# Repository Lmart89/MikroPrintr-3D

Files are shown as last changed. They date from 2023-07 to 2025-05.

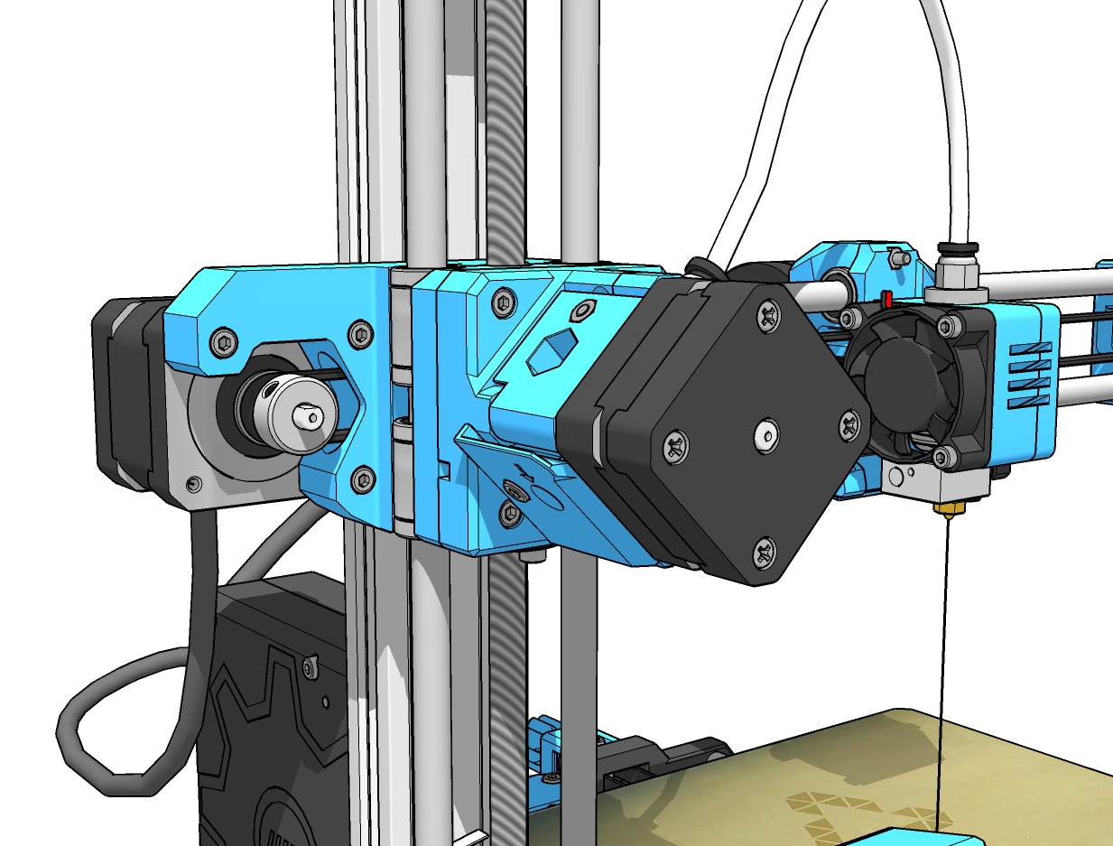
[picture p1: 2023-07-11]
Printable Parts/ME_Mini_3D_Printer/images/ME_-_mini_-_15.jpg

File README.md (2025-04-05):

<p align="center">
<img src=https://github.com/Lmart89/MikroPrintr-3D/assets/42391946/adc98b10-5be8-494d-9cd8-6f2932e612d1">
</p>

# MikroPrinter-3D.
## Una placa controladora de impresion 3d de bajo coste basada en Arduino.

<p align="center">

      

</p>

## 💡 Origen del Concepto

Mikropintr es el resultado propio de ideas tomadas de proyectos como Sinaptec (https://reprap.org/wiki/SinapTec), Morpheus (https://github.com/pscrespo/Morpheus-STM32) entre otros que ofrecen una solucion compacta y de bajo coste para la construccion de una placa controladora de impresion 3D. Sin embargo el gran limitante de estas placas es la necesidad de modificar el firmware para lograr compatiblidad con estos dispositovos, algo que requiere de mucho trabajo mas alla de la personalizacion, sin contar con los bugs resultantes en el proceso.
MikroPrintr pretende ofrecer una solucion asequible, a la vez de ser 100% compatible con Marlin, permitiendo desarrollar todo el potencial y la personalizacion a gusto. Para quepueda ser una placa compacta se opto por el arduino mega 2560 pro, una version reducida de Arduino Mega.

## :heavy_check_mark: Características de MikroPrintr.

- MCU: Arduino Mega 2560 Pro-Micro. Un Arduino Mega reducido en tamaño.

- Soporte Estándar de Marlin 2.0

- Diseñada bajo el standar RAMPS 1.4.

- Fabricación para uso de componentes THT (Trough Hole). 

- Tamaño Reducido. 103 mm x 90mm. a 1 sola capa, o producir a dos capas si se desea.

- Soporte Estándar de la smart reprap controller (lcd 2004) o la smart reprap full graphic controller (lcd 12864). no necesita la placa adaptadora para la conexion.
  
- Soporte para Módulo Wifi (esp8266-01 o esp8266-01s) Se recomienda la versión Esp-01s. se requiere un regulador de nivel lógico de 5v a 3.3V.

## :chart_with_upwards_trend: Estado del Proyecto.

   

:construction: Proyecto en construcción :construction:

## :books: Registro de cambios

###  Abril 2025.
- Se optimizo el diseño de la placa, y se corrigieron algunos detalles menores de la circuiteria.
- Rediseño de las piezas de la impresora con nuevas medidas, por un error de medicion en algunas de ellas.
- se libera la version 1H. de la placa.  

## :books: Recursos adicionales.

los siguientes modelos de impresoras pueden dar una fuente de inspiracion para el montaje  o diseño de una impresora 3d. uselos segun discrecion y precaucion propias.

### Me Mini 3d Printer - la mas completa y compleja.
  
 featured_preview_ME_-_mini_-_12

:earth_americas: link oficial. https://www.thingiverse.com/thing:5140212. 

### Skylab2 - una construccion sencilla y simple, recomendada para empezar. 

skylab2_1

:earth_americas: link oficial. https://www.thingiverse.com/thing:4624533.

### Prusa mini- la version mini de la prusa i3.
   Requiere la mayoria de sus piezas en ABS. 

prusa_mini

🌎 sitio oficial: https://www.printables.com/es/model/57214-mini-printable-parts/files

los archivos stl de estos modelos se encuentran en la carpeta "printable parts".

## :hammer_and_pick: Proyectos en conjunto. 
De momento estoy trabajando en el desarrollo de un software host propio para manejar la placa.

Si te interesa mi proyecto y deseas colaborar en el desarrollo, puedes contactarme, dejandome un mensaje o un request o solicitud de cambio via github.

Deseo que este proyecto pueda ser de utilidad para ti, maker. con :heart: desde Colombia 🇨🇴 para el mundo 🌎. :smile:

### <h4> :heavy_exclamation_mark: al hacer uso de los archivos publicados en este repositorio, el usuario acepta y asume su propia responsabilidad y riesgo por el uso y/o manipulacion de los archivos ofrecidos en este repositorio. :heavy_exclamation_mark: </h>

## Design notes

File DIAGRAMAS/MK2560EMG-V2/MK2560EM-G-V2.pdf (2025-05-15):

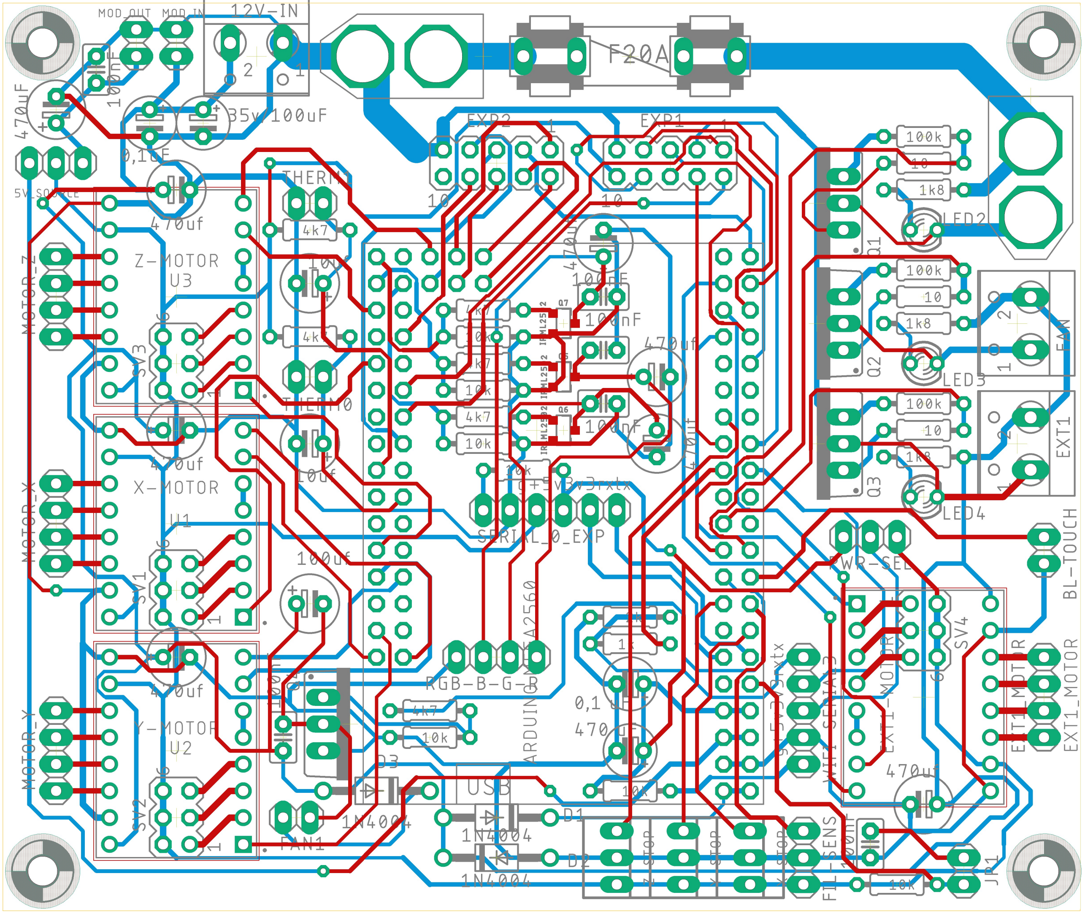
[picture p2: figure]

15/05/2025 3:54 p. m. f=2.00 D:\SOFT\MikroPrintr-3D-main\MikroPrintr-3D-main\DIAGRAMAS\MK2560EM-V2\MK2560EM-G v2.brd

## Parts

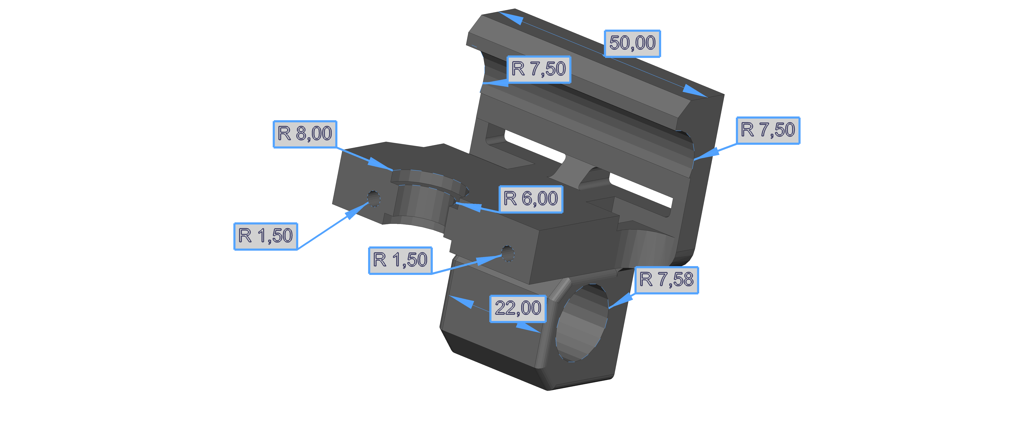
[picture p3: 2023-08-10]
Printable Parts/Skylab Variant/medidas_skylab/Extrusor_12 dimensiones 2.png

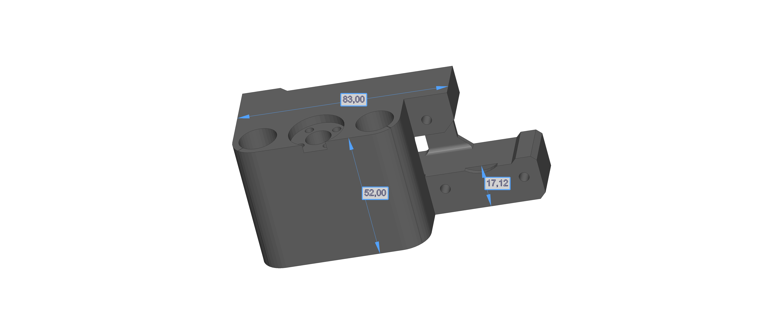
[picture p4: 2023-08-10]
Printable Parts/Skylab Variant/medidas_skylab/Z1 dimensiones 4.png

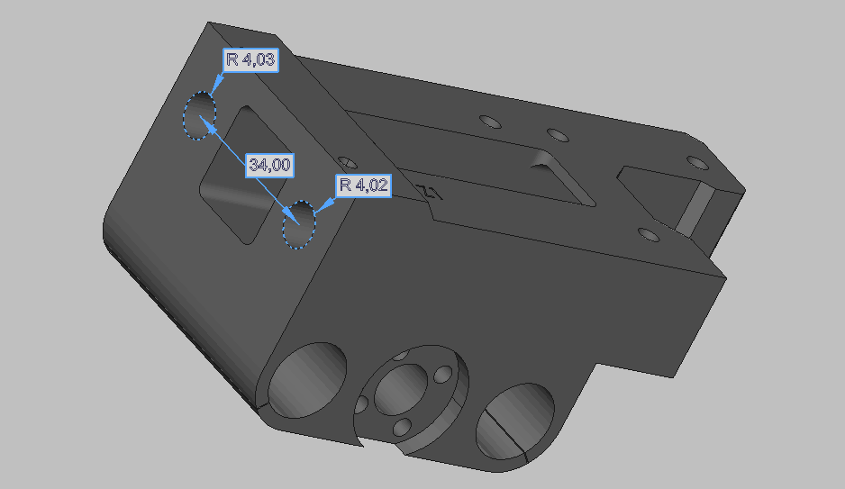
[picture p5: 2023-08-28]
Printable Parts/Skylab Variant/medidas_skylab/z1 dimensiones 5.png

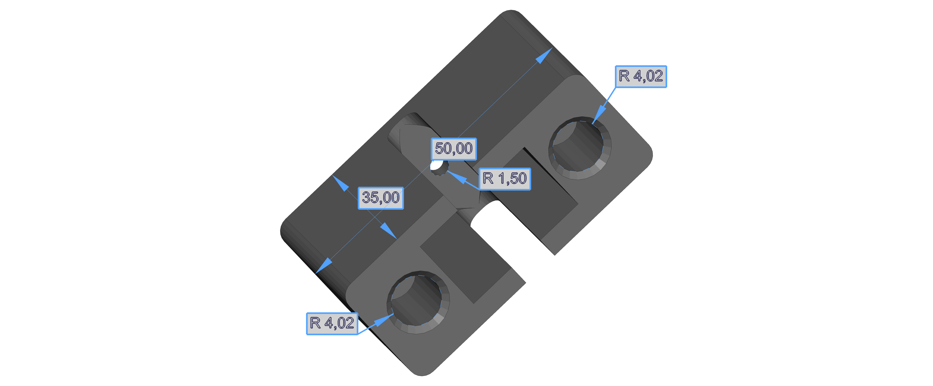
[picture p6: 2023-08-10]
Printable Parts/Skylab Variant/medidas_skylab/EjeX_polea dimensiones 1.png

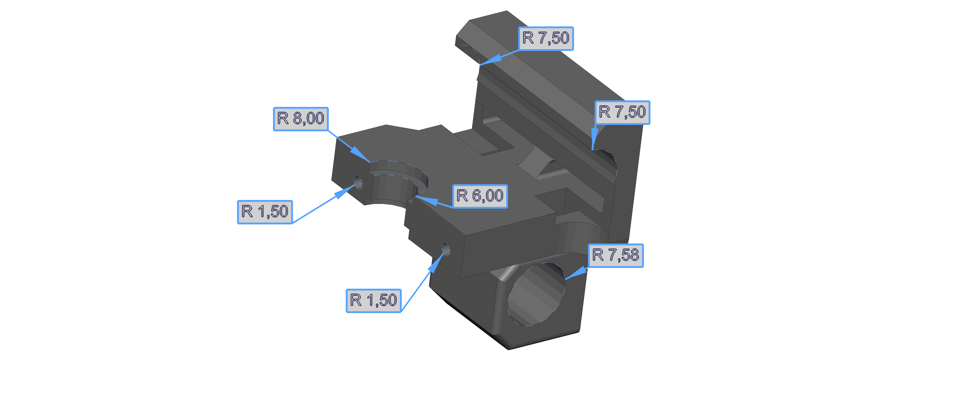
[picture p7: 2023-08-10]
Printable Parts/Skylab Variant/medidas_skylab/Extrusor_12 dimensiones 1.png

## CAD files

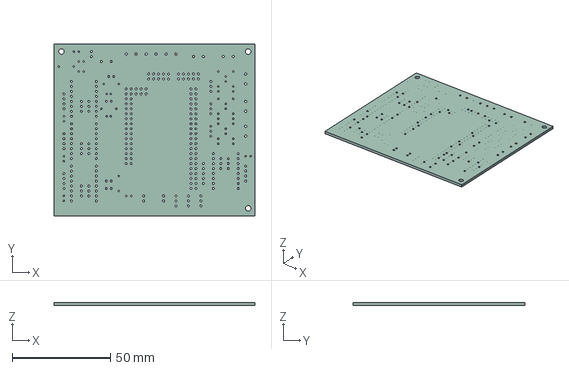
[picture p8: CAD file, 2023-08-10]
3D RENDERS/MK2560EM-G v1G-FLAT_PCB.step
102.5 x 87.6 x 1.60 mm

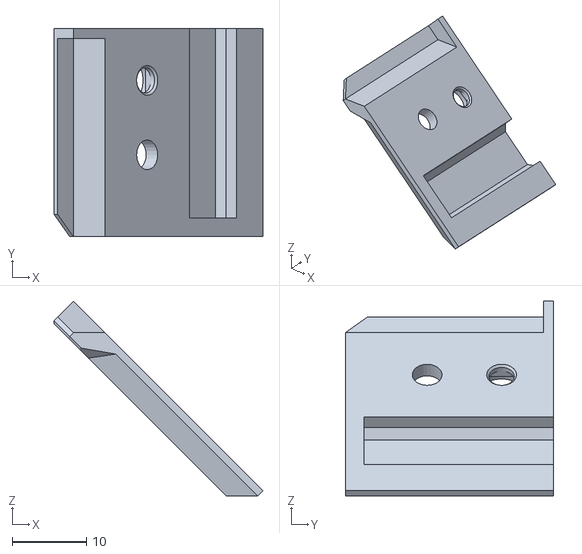
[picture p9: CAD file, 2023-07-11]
Printable Parts/ME_Mini_3D_Printer/files/Blue_-_Filament_Sensor_Cover.stl
28.1 x 28.0 x 26.2

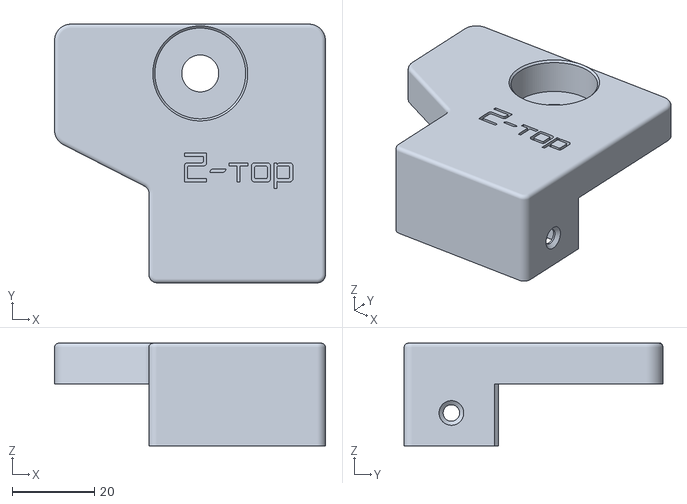
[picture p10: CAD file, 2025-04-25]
Printable Parts/MK-Parts V2/mk_z_top.stl
66.0 x 63.0 x 25.0

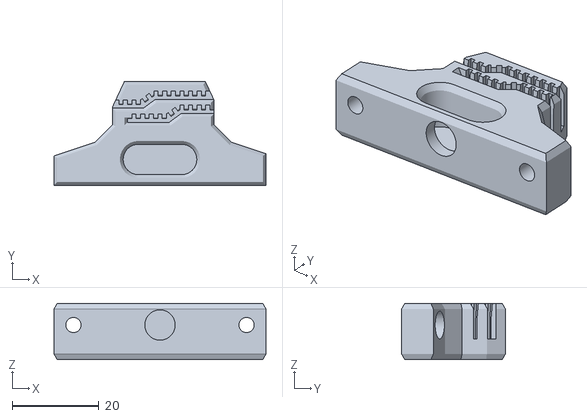
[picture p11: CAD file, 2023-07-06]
Printable Parts/Skylab Variant/MINI-y-belt-holder.stl
49.0 x 24.0 x 13.0

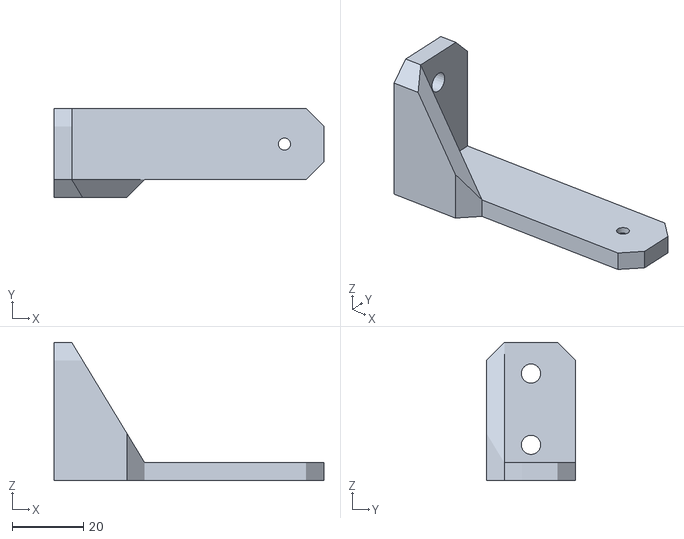
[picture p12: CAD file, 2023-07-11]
Printable Parts/ME_Mini_3D_Printer/files/Black_-_PSU_Left_Bracket.stl
75.7 x 25.0 x 38.7

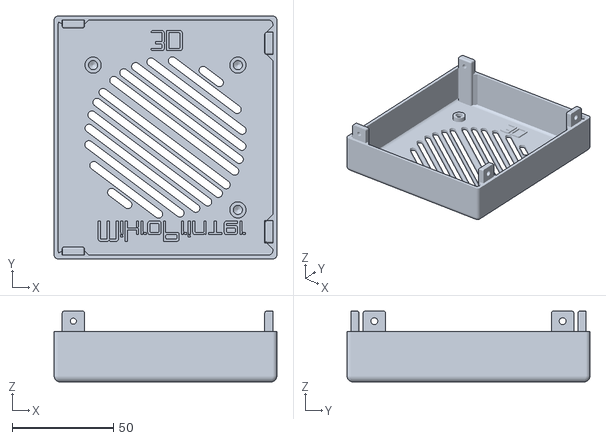
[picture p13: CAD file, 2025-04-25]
Printable Parts/MK-Parts V2/mk-board-case-top.stl
110.0 x 120.0 x 35.0

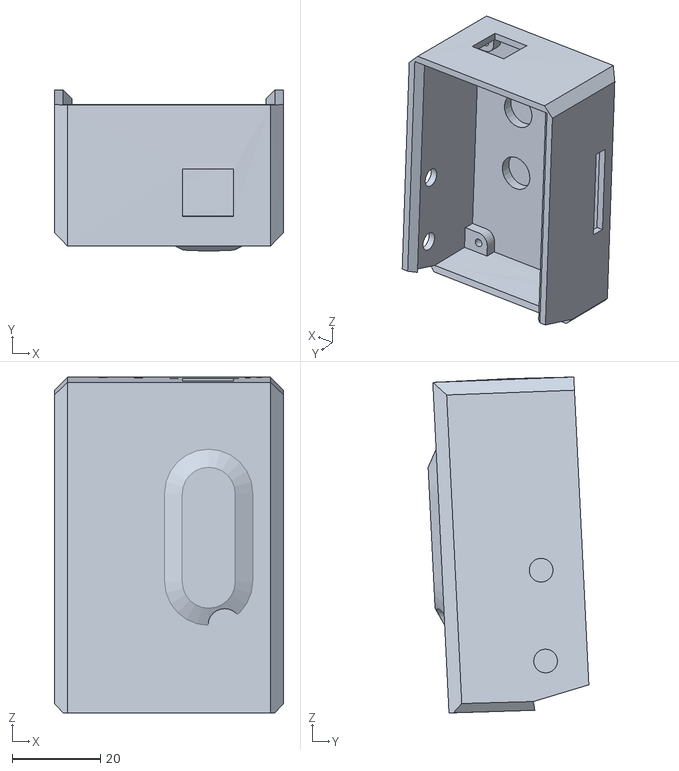
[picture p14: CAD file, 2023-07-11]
Printable Parts/ME_Mini_3D_Printer/files/Black_-_MKS_Adaptor_Housing.stl
52.0 x 36.4 x 76.2

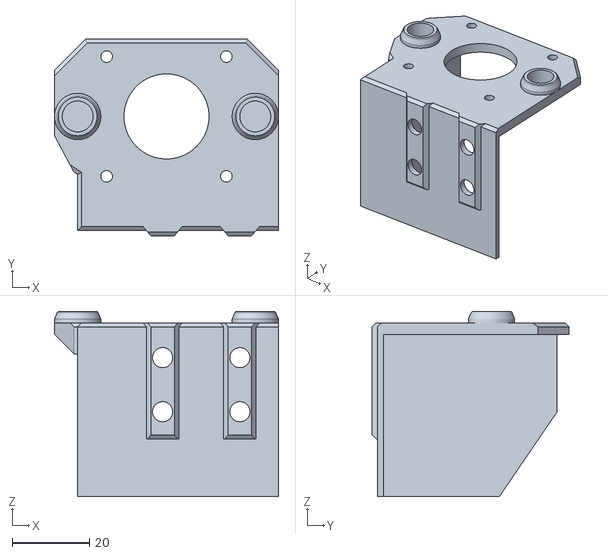
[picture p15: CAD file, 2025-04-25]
Printable Parts/MK-Parts V2/mk-z-motor-mount.stl
58.0 x 50.9 x 48.0

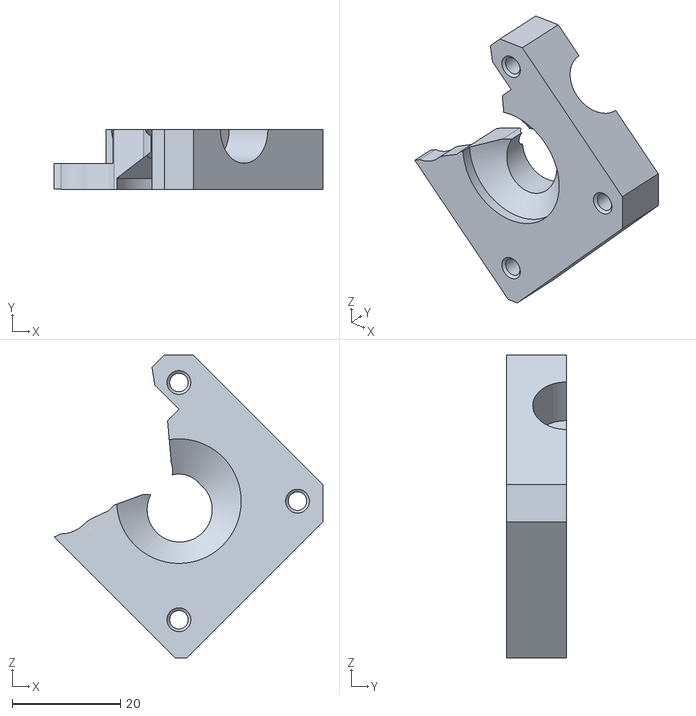
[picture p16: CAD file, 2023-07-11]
Printable Parts/ME_Mini_3D_Printer/files/Blue_-_Extruder_Motor_Mount.stl
49.7 x 11.0 x 56.0

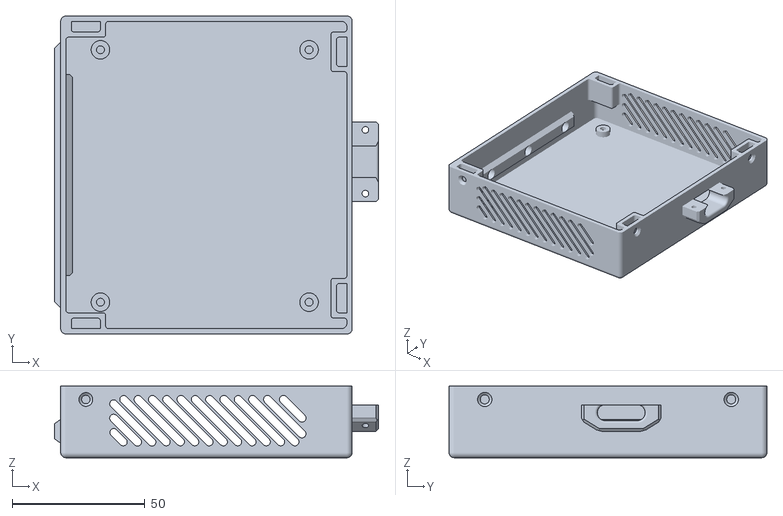
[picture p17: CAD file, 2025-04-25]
Printable Parts/MK-Parts V2/mk-board-case_v2.stl
122.4 x 120.0 x 27.0

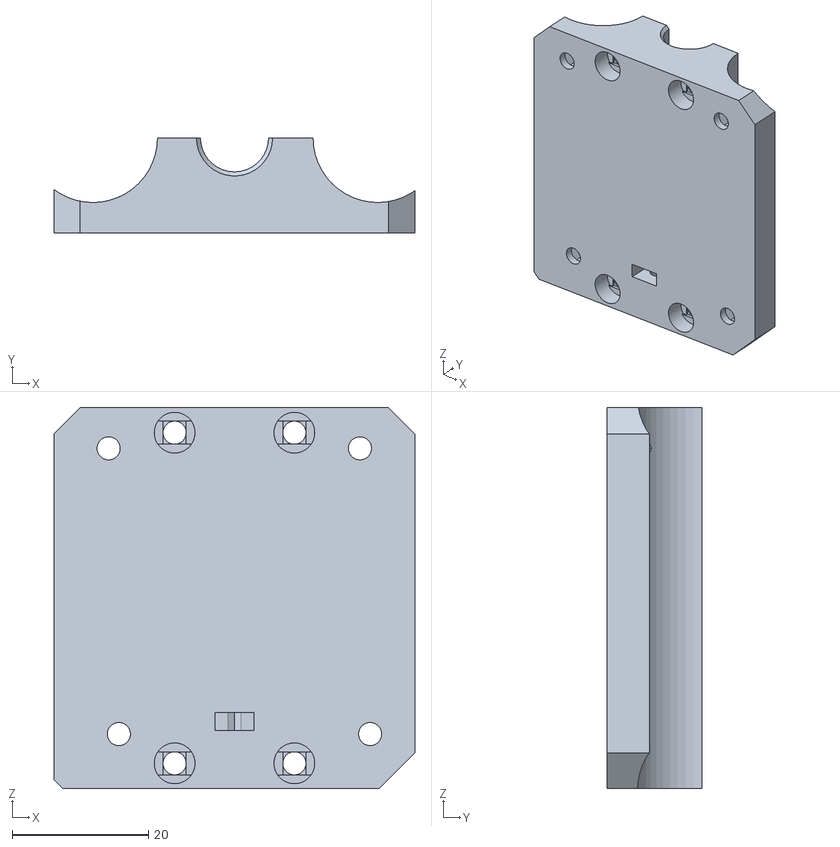
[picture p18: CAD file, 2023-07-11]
Printable Parts/ME_Mini_3D_Printer/files/Blue_-_X_Motor_Carriage_Front.stl
53.0 x 14.0 x 56.0

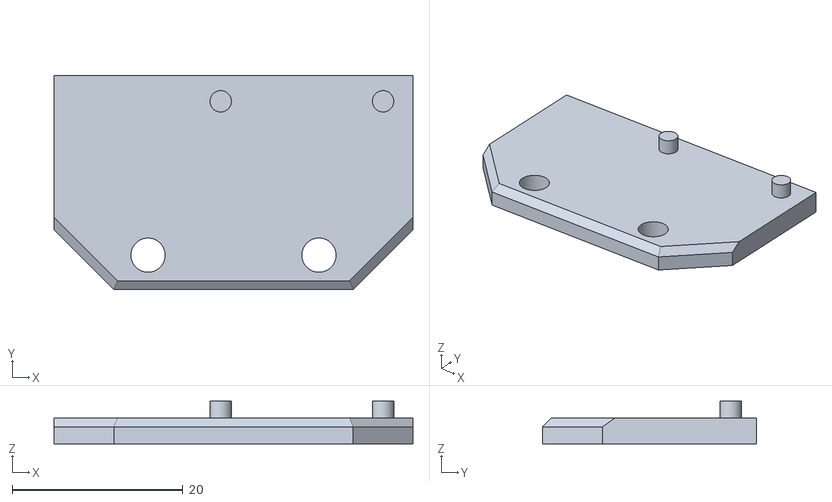
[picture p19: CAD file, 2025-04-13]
Printable Parts/MK-Parts V2/mk-limit-switch-z-mount.stl
42.0 x 25.0 x 5.00

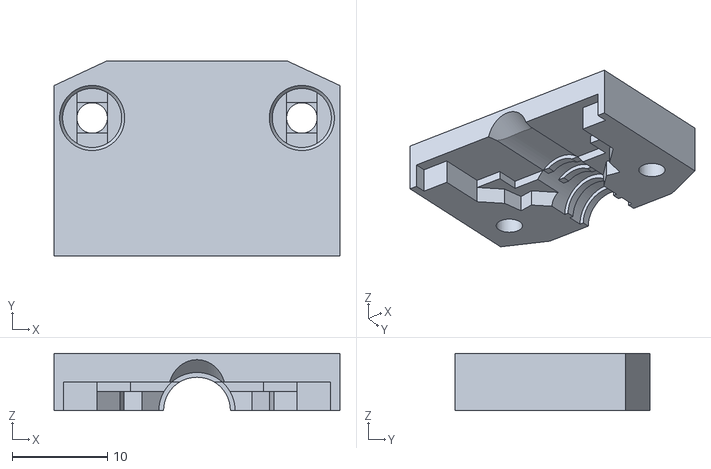
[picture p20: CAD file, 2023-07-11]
Printable Parts/ME_Mini_3D_Printer/files/Blue_-_Bed_Wire_Cover_B.stl
30.0 x 20.5 x 6.00

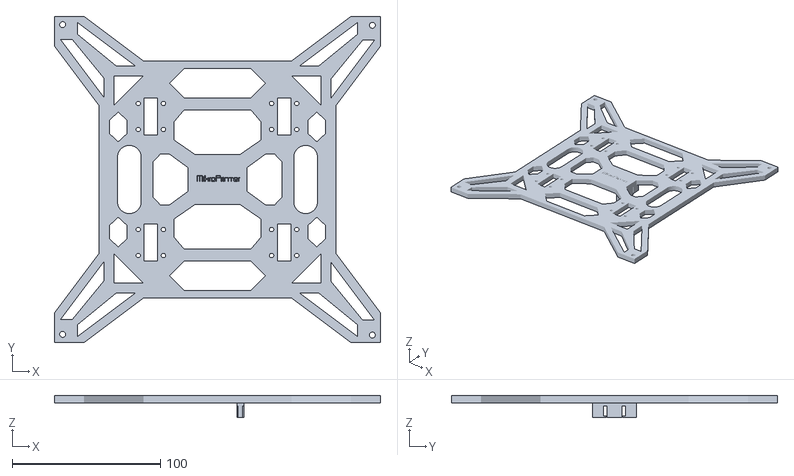
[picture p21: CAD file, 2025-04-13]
Printable Parts/MK-Parts V2/mk-bed-plate.stl
220.0 x 220.0 x 15.0

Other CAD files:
Printable Parts/ME_Mini_3D_Printer/files/Blue_-_Idler_Holder.stl
Printable Parts/MK-Parts V2/mk-cable-clip.stl
Printable Parts/ME_Mini_3D_Printer/files/Black_-_Back_Base_Plate.stl
Printable Parts/MK-Parts V2/mk_front_base_v2.stl
Printable Parts/ME_Mini_3D_Printer/files/Black_-_Bearing_Holder.stl
Printable Parts/ME_Mini_3D_Printer/files/Black_-_Extruder_Strain_Relief.stl
Printable Parts/ME_Mini_3D_Printer/files/Black_-_FS_Adapter.stl
Printable Parts/ME_Mini_3D_Printer/files/Black_-_FS_Leaver.stl
Printable Parts/ME_Mini_3D_Printer/files/Black_-_Front_Base_Plate.stl
Printable Parts/ME_Mini_3D_Printer/files/Black_-_MKS_Adaptor_Cover.stl
Printable Parts/ME_Mini_3D_Printer/files/Black_-_Makerbase_Board_Housing.stl
Printable Parts/ME_Mini_3D_Printer/files/Black_-_Makerbase_Cable_Clip.stl
Printable Parts/ME_Mini_3D_Printer/files/Black_-_Makerbase_Housing_Cover.stl
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

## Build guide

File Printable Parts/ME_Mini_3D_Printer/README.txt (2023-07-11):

ME - Mini 3D Printer by EdgarMata on Thingiverse: https://www.thingiverse.com/thing:5140212

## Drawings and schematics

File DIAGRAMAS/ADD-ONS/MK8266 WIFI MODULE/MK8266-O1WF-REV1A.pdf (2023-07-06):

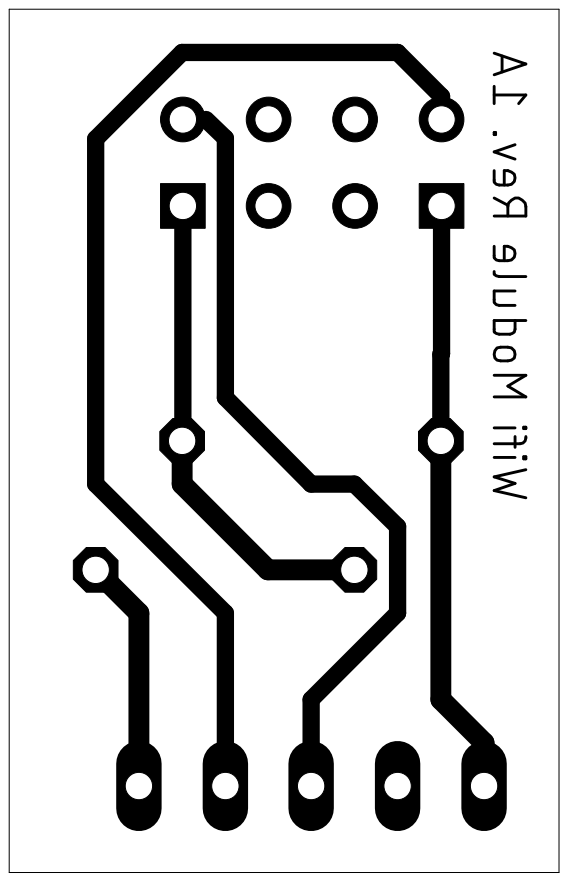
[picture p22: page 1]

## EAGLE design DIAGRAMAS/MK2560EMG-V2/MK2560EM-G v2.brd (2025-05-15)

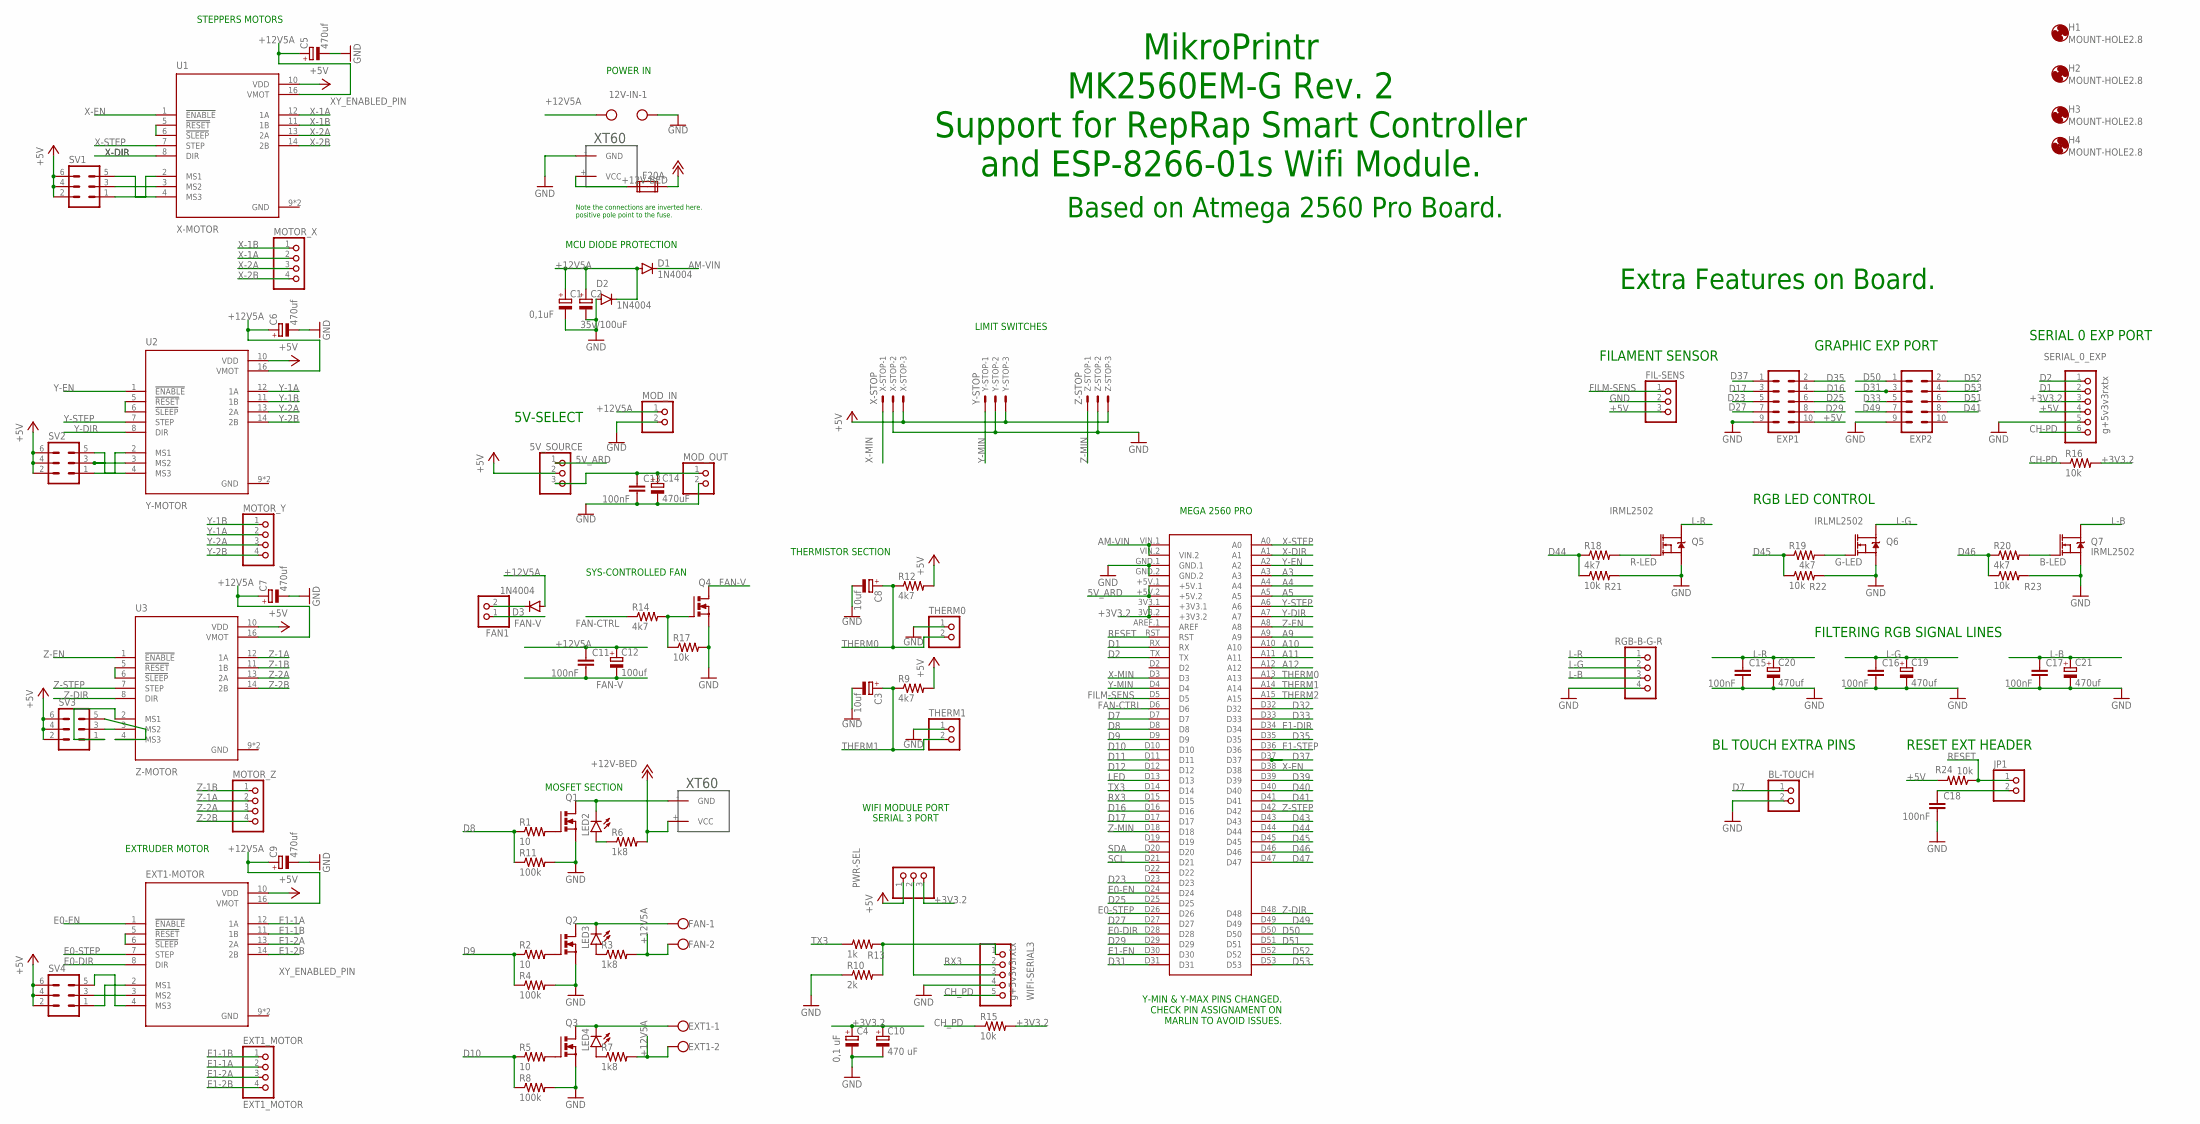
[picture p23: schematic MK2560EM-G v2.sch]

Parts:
5V_SOURCE: PINHD-1X3; 1X03
12V-IN: W237-102
ARD-MEGA: MEGA2560_MIKRO
BL-TOUCH: PINHD-1X2; 1X02
C1: 0,1uF; E2,5-5
C2: 35v/100uF; E2,5-5
C3, C8: 10uf; E2,5-6
C4: 0,1 uF; E2,5-5
C5, C6, C7, C9, C19, C20, C21: 470uf; E2,5-6E
C10: 470 uF; E2,5-5
C11, C13, C15, C16, C17, C18: 100nF; C2.5-2
C12: 100uf; E2,5-6
C14: 470uF; E2,5-6
D1, D2, D3: 1N4004; DO41-10
EXP1, EXP2: MA05-2
EXT1: W237-102
EXT1-MOTOR: A4988_STEPPER_MOTOR_DRIVER_CARRIER; MODULE_A4988_STEPPER_MOTOR_DRIVER_CARRIER
EXT1_MOTOR: EXT1_MOTOR; 1X04
F20A: FUSE2P; FUSE1
FAN: W237-102
FAN1: PINHD-1X2; 1X02
FIL-SENS: PINHD-1X3; 1X03
H1, H2, H3, H4: MOUNT-HOLE2.8; 2,8
JP1: PINHD-1X2; 1X02
LED2, LED3, LED4: LED3MM
MOD_IN: PINHD-1X2; 1X02
MOD_OUT: PINHD-1X2; 1X02
MOTOR_X: PINHD-1X4; 1X04
MOTOR_Y: PINHD-1X4; 1X04
MOTOR_Z: PINHD-1X4; 1X04
PWR-SEL: PINHD-1X3; 1X03
Q1, Q2, Q3, Q4: PMOSFET_NTO220BV; TO220BV
Q5, Q7: IRML2502; SOT23-3
Q6: IRLML2502; SOT23-3
R1, R2, R5: 10; 0204/7
R3, R6, R7: 1k8; 0204/7
R4, R8, R11: 100k; 0204/7
R9, R12, R14, R18, R19, R20: 4k7; 0204/7
R10: 2k; 0204/7
R13: 1k; 0204/7
R15, R16, R17, R21, R22, R23, R24: 10k; 0204/7
RGB-B-G-R: PINHD-1X4; 1X04
SERIAL_0_EXP: g+5v3v3rxtx; 1X06
SV1, SV2, SV3, SV4: MA03-2
THERM0, THERM1: PINHD-1X2; 1X02
U1: X-MOTOR; MODULE_A4988_STEPPER_MOTOR_DRIVER_CARRIER
U2: Y-MOTOR; MODULE_A4988_STEPPER_MOTOR_DRIVER_CARRIER
U3: Z-MOTOR; MODULE_A4988_STEPPER_MOTOR_DRIVER_CARRIER
U$1, U$2: XT60
WIFI-SERIAL3: g+5v3v3rxtx; 1X05
X-STOP: X-STOP; 22-23-2031
Y-STOP: Y-STOP; 22-23-2031
Z-STOP: Z-STOP; 22-23-2031

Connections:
5V_ARD: 5V_SOURCE.1, ARD-MEGA.+5V.1, ARD-MEGA.+5V.2
+3V3.2: ARD-MEGA.3V3.1 (+3V3.1), ARD-MEGA.3V3.2 (+3V3.2), C4.+, C10.+, PWR-SEL.3, R15.2, R16.2, SERIAL_0_EXP.3
+5V: 5V_SOURCE.2, EXP1.10, EXT1-MOTOR.10 (VDD), FIL-SENS.3, PWR-SEL.1, R9.2, R12.2, R24.2, SERIAL_0_EXP.4, SV1.2, SV1.4, SV1.6, SV2.2, SV2.4, SV2.6, SV3.2, SV3.4, SV3.6, SV4.2, SV4.4, SV4.6, U1.10 (VDD), U2.10 (VDD), U3.10 (VDD), X-STOP.3, Y-STOP.3, Z-STOP.3
+12V: F20A.2A, R6.2, U$2.+ (VCC)
+12V5A: 12V-IN.2, C1.+, C2.+, C5.+, C6.+, C7.+, C9.+, C11.1, C12.+, D1.A, D2.C, D3.A, EXT1.2, EXT1-MOTOR.16 (VMOT), FAN.2, MOD_IN.1, R3.2, R7.2, U1.16 (VMOT), U2.16 (VMOT), U3.16 (VMOT)
A3: ARD-MEGA.A3
A4: ARD-MEGA.A4
A5: ARD-MEGA.A5
A9: ARD-MEGA.A9
A10: ARD-MEGA.A10
A11: ARD-MEGA.A11
A12: ARD-MEGA.A12
AM-VIN: ARD-MEGA.VIN.1, ARD-MEGA.VIN.2, D1.C
B-LED: Q7.1 (G), R20.2
CH-PD: R16.1, SERIAL_0_EXP.6
CH_PD: R15.1, WIFI-SERIAL3.5
D1: ARD-MEGA.RX, SERIAL_0_EXP.2
D2: ARD-MEGA.TX, SERIAL_0_EXP.1
D7: ARD-MEGA.D7, BL-TOUCH.1
D8: ARD-MEGA.D8, R1.1, R11.1
D9: ARD-MEGA.D9, R2.1, R4.1
D10: ARD-MEGA.D10, R5.1, R8.1
D11: ARD-MEGA.D11
D12: ARD-MEGA.D12
D16: ARD-MEGA.D16, EXP1.4
D17: ARD-MEGA.D17, EXP1.3
D23: ARD-MEGA.D23, EXP1.5
D25: ARD-MEGA.D25, EXP1.6
D27: ARD-MEGA.D27, EXP1.7
D29: ARD-MEGA.D29, EXP1.8
D31: ARD-MEGA.D31, EXP2.3
D32: ARD-MEGA.D32
D33: ARD-MEGA.D33, EXP2.5
D35: ARD-MEGA.D35, EXP1.2
D37: ARD-MEGA.D37, EXP1.1
D39: ARD-MEGA.D39
D40: ARD-MEGA.D40
D41: ARD-MEGA.D41, EXP2.8
D43: ARD-MEGA.D43
D44: ARD-MEGA.D44, R18.1, R21.1
D45: ARD-MEGA.D45, R19.1, R22.1
D46: ARD-MEGA.D46, R20.1, R23.1
D47: ARD-MEGA.D47
D49: ARD-MEGA.D49, EXP2.7
D50: ARD-MEGA.D50, EXP2.1
D51: ARD-MEGA.D51, EXP2.6
D52: ARD-MEGA.D52, EXP2.2
D53: ARD-MEGA.D53, EXP2.4
E0-DIR: ARD-MEGA.D28, EXT1-MOTOR.8 (DIR)
E0-EN: ARD-MEGA.D24, EXT1-MOTOR.1 (!ENABLE)
E0-STEP: ARD-MEGA.D26, EXT1-MOTOR.7 (STEP)
E1-1A: EXT1-MOTOR.12 (1A), EXT1_MOTOR.2
E1-1B: EXT1-MOTOR.11 (1B), EXT1_MOTOR.1
E1-2A: EXT1-MOTOR.13 (2A), EXT1_MOTOR.3
E1-2B: EXT1-MOTOR.14 (2B), EXT1_MOTOR.4
E1-DIR: ARD-MEGA.D34
E1-EN: ARD-MEGA.D30
E1-STEP: ARD-MEGA.D36
FAN-CTRL: ARD-MEGA.D6, R14.1
FAN-V: C11.2, C12.-, FAN1.1, Q4.D
FILM-SENS: ARD-MEGA.D5, FIL-SENS.1
G-LED: Q6.1 (G), R19.2
GND: 12V-IN.1, ARD-MEGA.GND.1, ARD-MEGA.GND.2, BL-TOUCH.2, C1.-, C2.-, C3.-, C4.-, C5.-, C6.-, C7.-, C8.-, C9.-, C10.-, C13.2, C14.-, C15.2, C16.2, C17.2, C18.2, C19.-, C20.-, C21.-, D2.A, EXP1.9, EXP2.9, EXT1-MOTOR.9 (GND), EXT1-MOTOR.15 (GND), FIL-SENS.2, MOD_IN.2, MOD_OUT.2, Q1.S, Q2.S, Q3.S, Q4.S, Q5.2 (S), Q6.2 (S), Q7.2 (S), R4.2, R8.2, R10.1, R11.2, R17.2, R21.2, R22.2, R23.2, RGB-B-G-R.4, SERIAL_0_EXP.5, THERM0.1, THERM1.1, U1.9 (GND), U1.15 (GND), U2.9 (GND), U2.15 (GND), U3.9 (GND), U3.15 (GND), U$1.- (GND), WIFI-SERIAL3.4, X-STOP.2, Y-STOP.2, Z-STOP.2
L-B: C17.1, C21.+, Q7.3 (D), RGB-B-G-R.3
L-G: C16.1, C19.+, Q6.3 (D), RGB-B-G-R.2
L-R: C15.1, C20.+, Q5.3 (D), RGB-B-G-R.1
LED: ARD-MEGA.D13
unnamed: Q2.G, R2.2
unnamed: FAN.1, LED3.K (C), Q2.D
unnamed: LED3.A, R3.1
unnamed: Q3.G, R5.2
unnamed: EXT1.1, LED4.K (C), Q3.D
unnamed: LED4.A, R7.1
unnamed: LED2.K (C), Q1.D, U$2.- (GND)
unnamed: LED2.A, R6.1
unnamed: SV1.5, U1.4 (MS3)
unnamed: SV1.3, U1.3 (MS2)
unnamed: SV1.1, U1.2 (MS1)
unnamed: U2.5 (!RESET), U2.6 (!SLEEP)
unnamed: U1.5 (!RESET), U1.6 (!SLEEP)
unnamed: SV2.1, U2.2 (MS1)
unnamed: SV2.3, U2.3 (MS2)
unnamed: SV2.5, U2.4 (MS3)
unnamed: U3.5 (!RESET), U3.6 (!SLEEP)
unnamed: R10.2, R13.2, WIFI-SERIAL3.1
unnamed: SV3.3, U3.3 (MS2)
unnamed: Q1.G, R1.2
unnamed: SV3.1, U3.2 (MS1)
unnamed: SV3.5, U3.4 (MS3)
unnamed: EXT1-MOTOR.5 (!RESET), EXT1-MOTOR.6 (!SLEEP)
unnamed: EXT1-MOTOR.3 (MS2), SV4.3
unnamed: EXT1-MOTOR.4 (MS3), SV4.5
unnamed: EXT1-MOTOR.2 (MS1), SV4.1
unnamed: Q4.G, R14.2, R17.1
unnamed: D3.C, FAN1.2
unnamed: F20A.1A, U$1.+ (VCC)
unnamed: 5V_SOURCE.3, C13.1, C14.+, MOD_OUT.1
unnamed: PWR-SEL.2, WIFI-SERIAL3.3
unnamed: C18.1, JP1.2
R-LED: Q5.1 (G), R18.2
RESET: ARD-MEGA.RST, JP1.1, R24.1
RX3: ARD-MEGA.D15, WIFI-SERIAL3.2
SCL: ARD-MEGA.D21
SDA: ARD-MEGA.D20
THERM0: ARD-MEGA.A13, C8.+, R12.1, THERM0.2
THERM1: ARD-MEGA.A14, C3.+, R9.1, THERM1.2
THERM2: ARD-MEGA.A15
TX3: ARD-MEGA.D14, R13.1
X-1A: MOTOR_X.2, U1.12 (1A)
X-1B: MOTOR_X.1, U1.11 (1B)
X-2A: MOTOR_X.3, U1.13 (2A)
X-2B: MOTOR_X.4, U1.14 (2B)
X-DIR: ARD-MEGA.A1, U1.8 (DIR)
X-EN: ARD-MEGA.D38, U1.1 (!ENABLE)
X-MIN: ARD-MEGA.D3, X-STOP.1
X-STEP: ARD-MEGA.A0, U1.7 (STEP)
Y-1A: MOTOR_Y.2, U2.12 (1A)
Y-1B: MOTOR_Y.1, U2.11 (1B)
Y-2A: MOTOR_Y.3, U2.13 (2A)
Y-2B: MOTOR_Y.4, U2.14 (2B)
Y-DIR: ARD-MEGA.A7, U2.8 (DIR)
Y-EN: ARD-MEGA.A2, U2.1 (!ENABLE)
Y-MIN: ARD-MEGA.D4, Y-STOP.1
Y-STEP: ARD-MEGA.A6, U2.7 (STEP)
Z-1A: MOTOR_Z.2, U3.12 (1A)
Z-1B: MOTOR_Z.1, U3.11 (1B)
Z-2A: MOTOR_Z.3, U3.13 (2A)
Z-2B: MOTOR_Z.4, U3.14 (2B)
Z-DIR: ARD-MEGA.D48, U3.8 (DIR)
Z-EN: ARD-MEGA.A8, U3.1 (!ENABLE)
Z-MIN: ARD-MEGA.D18, Z-STOP.1
Z-STEP: ARD-MEGA.D42, U3.7 (STEP)

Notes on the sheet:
MikroPrintr MK2560EM-G Rev. 2 Support for RepRap Smart Controller and ESP-8266-01s Wifi Module.
Based on Atmega 2560 Pro Board.
Note the connections are inverted here. positive pole point to the fuse.
MCU DIODE PROTECTION
MOSFET SECTION
THERMISTOR SECTION
GRAPHIC EXP PORT
MEGA 2560 PRO
WIFI MODULE PORT
STEPPERS MOTORS
EXTRUDER MOTOR
LIMIT SWITCHES
SYS-CONTROLLED FAN
POWER IN
Y-MIN & Y-MAX PINS CHANGED. CHECK PIN ASSIGNAMENT ON MARLIN TO AVOID ISSUES.
5V-SELECT
SERIAL 3 PORT
SERIAL 0 EXP PORT
Extra Features on Board.
RGB LED CONTROL
FILTERING RGB SIGNAL LINES
FILAMENT SENSOR
RESET EXT HEADER
BL TOUCH EXTRA PINS

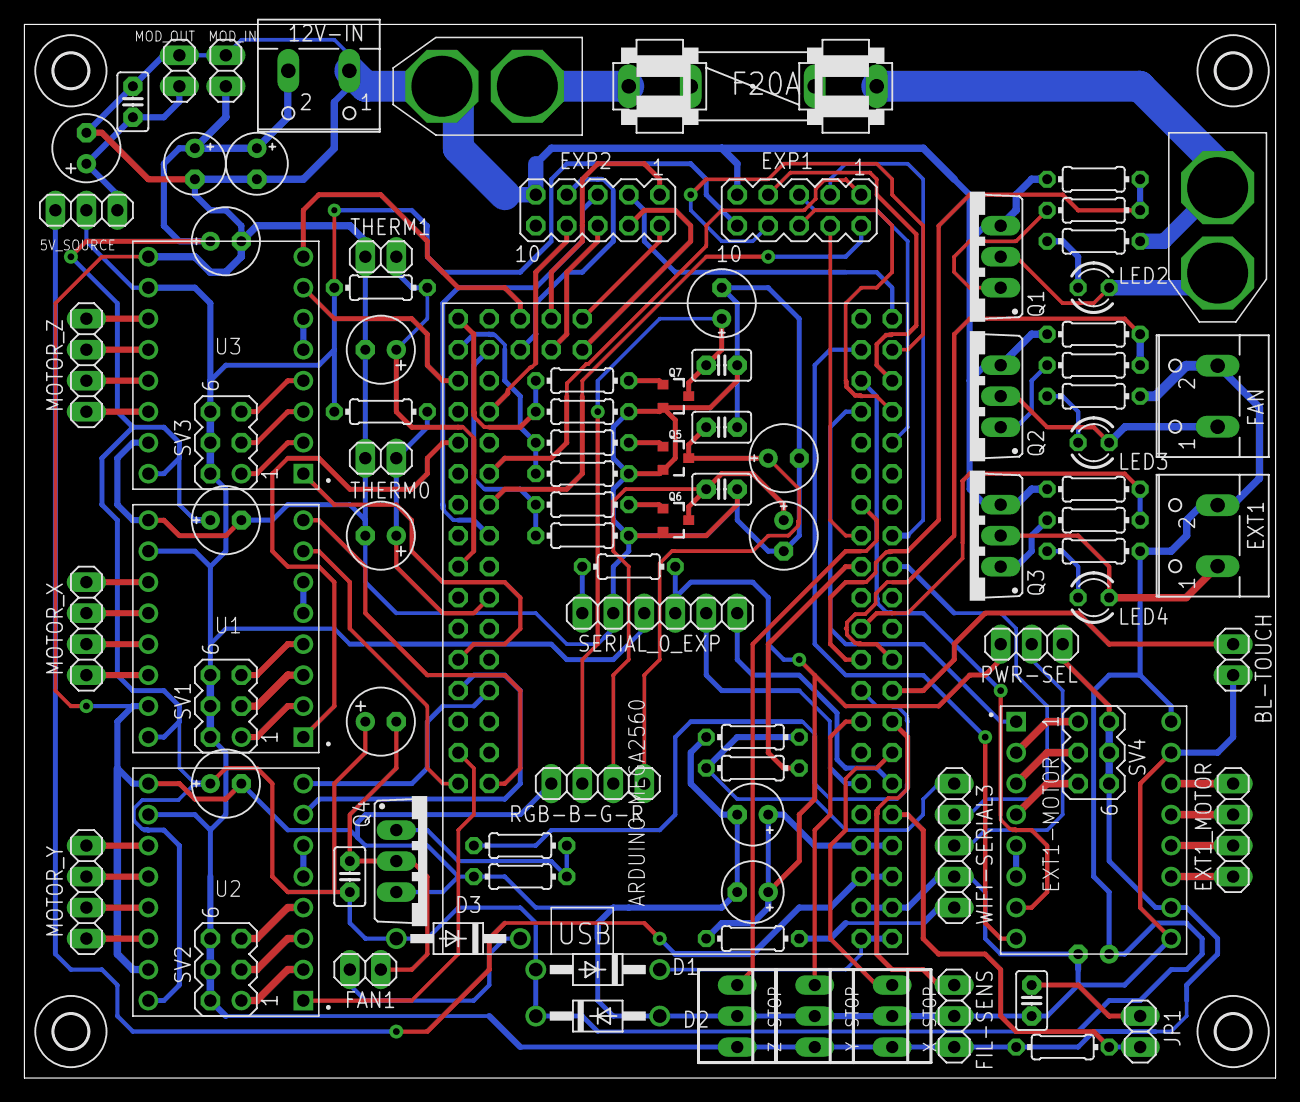
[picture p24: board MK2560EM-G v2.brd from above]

Board: 2 copper layers, 102.5 x 86.4 mm, 99 parts (1 on the bottom side), 111 nets.

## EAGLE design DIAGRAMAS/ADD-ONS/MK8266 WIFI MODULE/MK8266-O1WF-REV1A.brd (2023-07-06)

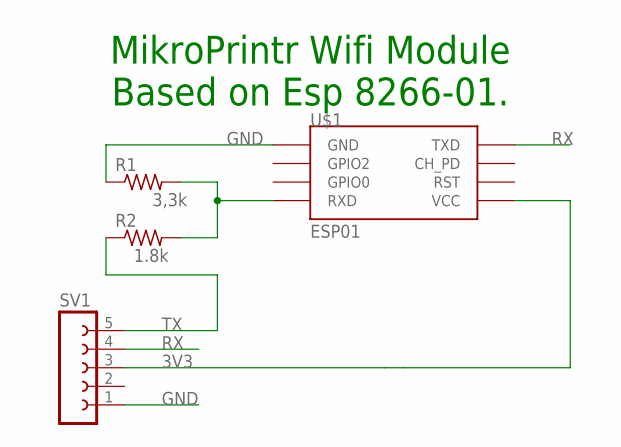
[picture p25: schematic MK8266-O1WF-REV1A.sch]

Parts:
R1: 3,3k; 0204/7
R2: 1.8k; 0204/7
SV1: FE05-1
U$1: ESP01

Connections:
3V3: SV1.3, U$1.VCC
GND: R1.1, SV1.1, U$1.GND
unnamed: R1.2, R2.2, U$1.RX (RXD)
RX: SV1.4, U$1.TX (TXD)
TX: R2.1, SV1.5

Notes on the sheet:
MikroPrintr Wifi Module Based on Esp 8266-01.

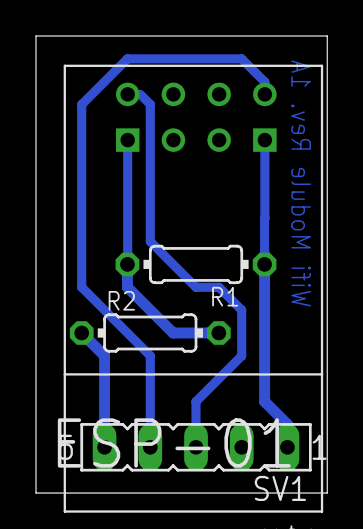
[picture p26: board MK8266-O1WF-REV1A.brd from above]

Board: 2 copper layers, 16.2 x 25.4 mm, 4 parts (0 on the bottom side), 5 nets.

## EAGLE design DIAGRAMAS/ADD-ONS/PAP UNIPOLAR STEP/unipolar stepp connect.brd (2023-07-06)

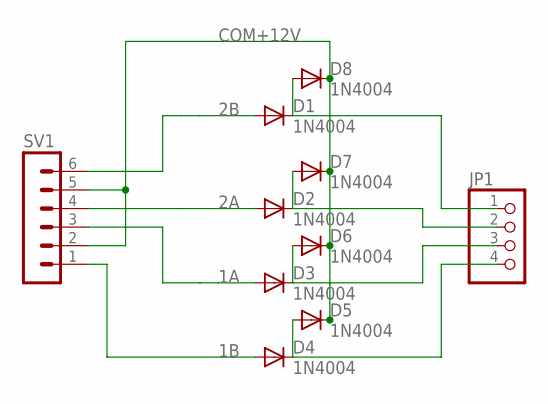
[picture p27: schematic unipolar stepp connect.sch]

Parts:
D1, D2, D3, D4, D5, D6, D7, D8: 1N4004; DO41-10
JP1: PINHD-1X4/90; 1X04/90
SV1: MA06-1

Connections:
1A: D3.A, SV1.3
1B: D4.A, SV1.1
2A: D2.A, SV1.4
2B: D1.A, SV1.6
COM+12V: D5.C, D6.C, D7.C, D8.C, SV1.2, SV1.5
unnamed: D1.C, D8.A, JP1.1
unnamed: D2.C, D7.A, JP1.2
unnamed: D3.C, D6.A, JP1.3
unnamed: D4.C, D5.A, JP1.4

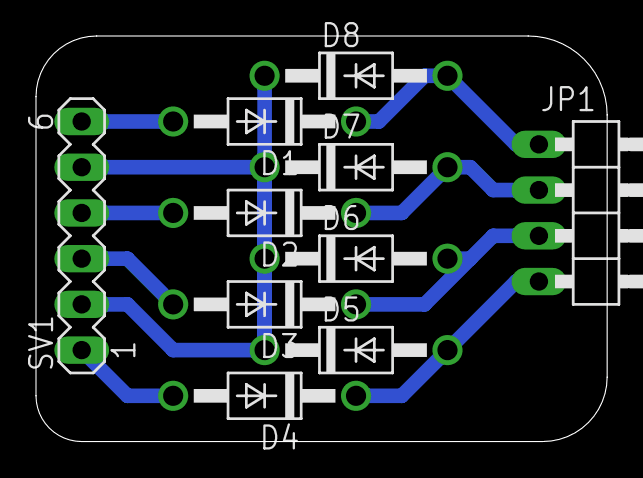
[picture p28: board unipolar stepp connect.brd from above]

Board: 2 copper layers, 31.7 x 22.5 mm, 10 parts (0 on the bottom side), 9 nets.

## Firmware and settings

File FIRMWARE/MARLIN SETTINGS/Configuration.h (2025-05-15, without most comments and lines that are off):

#pragma once
#define CONFIGURATION_H_VERSION 01010000
#define STRING_CONFIG_H_AUTHOR "(LUIS E MTZ S, V1.1)" // Who made the changes.
#define SHOW_BOOTSCREEN
  #define MOTHERBOARD BOARD_RAMPS_14_EFB
#define SERIAL_PORT 0
#define BAUDRATE 250000
#define SERIAL_PORT_3 1
#define BAUDRATE_3 115200   // :[2400, 9600, 19200, 38400, 57600, 115200, 250000, 500000, 1000000] Enable to override BAUDRATE
#define CUSTOM_MACHINE_NAME "MikroPrinter 3D"
#define X_DRIVER_TYPE  DRV8825
#define Y_DRIVER_TYPE  DRV8825
#define Z_DRIVER_TYPE  DRV8825
#define E0_DRIVER_TYPE DRV8825
#define EXTRUDERS 1
#define DEFAULT_NOMINAL_FILAMENT_DIA 1.75
#define TEMP_SENSOR_0 1
#define TEMP_SENSOR_1 0
#define TEMP_SENSOR_2 0
#define TEMP_SENSOR_3 0
#define TEMP_SENSOR_4 0
#define TEMP_SENSOR_5 0
#define TEMP_SENSOR_6 0
#define TEMP_SENSOR_7 0
#define TEMP_SENSOR_BED 1
#define TEMP_SENSOR_PROBE 0
#define TEMP_SENSOR_CHAMBER 0
#define TEMP_SENSOR_COOLER 0
#define TEMP_SENSOR_BOARD 0
#define TEMP_SENSOR_REDUNDANT 0
#define DUMMY_THERMISTOR_998_VALUE  25
#define DUMMY_THERMISTOR_999_VALUE 100
#if TEMP_SENSOR_IS_MAX_TC(0)
  #define MAX31865_SENSOR_OHMS_0      100 // (Ω) Typically 100 or 1000 (PT100 or PT1000)
  #define MAX31865_CALIBRATION_OHMS_0 430 // (Ω) Typically 430 for Adafruit PT100; 4300 for Adafruit PT1000
#endif
#if TEMP_SENSOR_IS_MAX_TC(1)
  #define MAX31865_SENSOR_OHMS_1      100
  #define MAX31865_CALIBRATION_OHMS_1 430
#endif
#if TEMP_SENSOR_IS_MAX_TC(2)
  #define MAX31865_SENSOR_OHMS_2      100
  #define MAX31865_CALIBRATION_OHMS_2 430
#endif
#if HAS_E_TEMP_SENSOR
  #define TEMP_RESIDENCY_TIME         10  // (seconds) Time to wait for hotend to "settle" in M109
  #define TEMP_WINDOW                  1  // (°C) Temperature proximity for the "temperature reached" timer
  #define TEMP_HYSTERESIS              3  // (°C) Temperature proximity considered "close enough" to the target
#endif
#if TEMP_SENSOR_BED
  #define TEMP_BED_RESIDENCY_TIME     10  // (seconds) Time to wait for bed to "settle" in M190
  #define TEMP_BED_WINDOW              1  // (°C) Temperature proximity for the "temperature reached" timer
  #define TEMP_BED_HYSTERESIS          3  // (°C) Temperature proximity considered "close enough" to the target
#endif
#if TEMP_SENSOR_CHAMBER
  #define TEMP_CHAMBER_RESIDENCY_TIME 10  // (seconds) Time to wait for chamber to "settle" in M191
  #define TEMP_CHAMBER_WINDOW          1  // (°C) Temperature proximity for the "temperature reached" timer
  #define TEMP_CHAMBER_HYSTERESIS      3  // (°C) Temperature proximity considered "close enough" to the target
#endif
#if TEMP_SENSOR_REDUNDANT
  #define TEMP_SENSOR_REDUNDANT_SOURCE    E1  // The sensor that will provide the redundant reading.
  #define TEMP_SENSOR_REDUNDANT_TARGET    E0  // The sensor that we are providing a redundant reading for.
  #define TEMP_SENSOR_REDUNDANT_MAX_DIFF  10  // (°C) Temperature difference that will trigger a print abort.
#endif
#define HEATER_0_MINTEMP   5
#define HEATER_1_MINTEMP   5
#define HEATER_2_MINTEMP   5
#define HEATER_3_MINTEMP   5
#define HEATER_4_MINTEMP   5
#define HEATER_5_MINTEMP   5
#define HEATER_6_MINTEMP   5
#define HEATER_7_MINTEMP   5
#define BED_MINTEMP        5
#define CHAMBER_MINTEMP    5
#define HEATER_0_MAXTEMP 275
#define HEATER_1_MAXTEMP 275
#define HEATER_2_MAXTEMP 275
#define HEATER_3_MAXTEMP 275
#define HEATER_4_MAXTEMP 275
#define HEATER_5_MAXTEMP 275
#define HEATER_6_MAXTEMP 275
#define HEATER_7_MAXTEMP 275
#define BED_MAXTEMP      150
#define CHAMBER_MAXTEMP  60
#define HOTEND_OVERSHOOT 15   // (°C) Forbid temperatures over MAXTEMP - OVERSHOOT
#define BED_OVERSHOOT    10   // (°C) Forbid temperatures over MAXTEMP - OVERSHOOT
#define COOLER_OVERSHOOT  2   // (°C) Forbid temperatures closer than OVERSHOOT
#define PIDTEMP           // See the PID Tuning Guide at https://reprap.org/wiki/PID_Tuning
#define PID_MAX  255      // Limit hotend current while PID is active (see PID_FUNCTIONAL_RANGE below); 255=full current
#define PID_K1     0.95   // Smoothing factor within any PID loop
    #define DEFAULT_Kp  22.20
    #define DEFAULT_Ki   1.08
    #define DEFAULT_Kd 114.00
#define MAX_BED_POWER 255 // limits duty cycle to bed; 255=full current
#define MAX_CHAMBER_POWER 255 // limits duty cycle to chamber heater; 255=full current
  #define PID_FUNCTIONAL_RANGE 10 // If the temperature difference between the target temperature and the actual temperature
#define PREVENT_COLD_EXTRUSION
#define EXTRUDE_MINTEMP 170
#define PREVENT_LENGTHY_EXTRUDE
#define EXTRUDE_MAXLENGTH 200
#define THERMAL_PROTECTION_HOTENDS // Enable thermal protection for all extruders
#define THERMAL_PROTECTION_BED     // Enable thermal protection for the heated bed
#define THERMAL_PROTECTION_CHAMBER // Enable thermal protection for the heated chamber
#define THERMAL_PROTECTION_COOLER  // Enable thermal protection for the laser cooling
#define USE_XMIN_PLUG
#define USE_YMIN_PLUG
#define USE_ZMIN_PLUG
#define ENDSTOPPULLUPS
#define X_MIN_ENDSTOP_INVERTING false // Set to true to invert the logic of the endstop.
#define Y_MIN_ENDSTOP_INVERTING false // Set to true to invert the logic of the endstop.
#define Z_MIN_ENDSTOP_INVERTING false // Set to true to invert the logic of the endstop.
#define I_MIN_ENDSTOP_INVERTING false // Set to true to invert the logic of the endstop.
#define J_MIN_ENDSTOP_INVERTING false // Set to true to invert the logic of the endstop.
#define K_MIN_ENDSTOP_INVERTING false // Set to true to invert the logic of the endstop.
#define U_MIN_ENDSTOP_INVERTING false // Set to true to invert the logic of the endstop.
#define V_MIN_ENDSTOP_INVERTING false // Set to true to invert the logic of the endstop.
#define W_MIN_ENDSTOP_INVERTING false // Set to true to invert the logic of the endstop.
#define X_MAX_ENDSTOP_INVERTING false // Set to true to invert the logic of the endstop.
#define Y_MAX_ENDSTOP_INVERTING false // Set to true to invert the logic of the endstop.
#define Z_MAX_ENDSTOP_INVERTING false // Set to true to invert the logic of the endstop.
#define I_MAX_ENDSTOP_INVERTING false // Set to true to invert the logic of the endstop.
#define J_MAX_ENDSTOP_INVERTING false // Set to true to invert the logic of the endstop.
#define K_MAX_ENDSTOP_INVERTING false // Set to true to invert the logic of the endstop.
#define U_MAX_ENDSTOP_INVERTING false // Set to true to invert the logic of the endstop.
#define V_MAX_ENDSTOP_INVERTING false // Set to true to invert the logic of the endstop.
#define W_MAX_ENDSTOP_INVERTING false // Set to true to invert the logic of the endstop.
#define Z_MIN_PROBE_ENDSTOP_INVERTING false // Set to true to invert the logic of the probe.
#define DEFAULT_AXIS_STEPS_PER_UNIT   { 80, 80, 400, 500 }
#define DEFAULT_MAX_FEEDRATE          { 300, 300, 5, 25 }
#define DEFAULT_MAX_ACCELERATION      { 3000, 3000, 100, 10000 }
#define DEFAULT_ACCELERATION          3000    // X, Y, Z and E acceleration for printing moves
#define DEFAULT_RETRACT_ACCELERATION  3000    // E acceleration for retracts
#define DEFAULT_TRAVEL_ACCELERATION   3000    // X, Y, Z acceleration for travel (non printing) moves
#define DEFAULT_EJERK    5.0  // May be used by Linear Advance
  #define JUNCTION_DEVIATION_MM 0.013 // (mm) Distance from real junction edge
  #define JD_HANDLE_SMALL_SEGMENTS    // Use curvature estimation instead of just the junction angle
#define Z_MIN_PROBE_USES_Z_MIN_ENDSTOP_PIN
#define NOZZLE_TO_PROBE_OFFSET { 10, 10, 0 }
#define PROBING_MARGIN 10
#define XY_PROBE_FEEDRATE (133*60)
#define Z_PROBE_FEEDRATE_FAST (4*60)
#define Z_PROBE_FEEDRATE_SLOW (Z_PROBE_FEEDRATE_FAST / 2)
#define Z_CLEARANCE_DEPLOY_PROBE   10 // (mm) Z Clearance for Deploy/Stow
#define Z_CLEARANCE_BETWEEN_PROBES  5 // (mm) Z Clearance between probe points
#define Z_CLEARANCE_MULTI_PROBE     5 // (mm) Z Clearance between multiple probes
#define Z_PROBE_LOW_POINT          -2 // (mm) Farthest distance below the trigger-point to go before stopping
#define Z_PROBE_OFFSET_RANGE_MIN -20
#define Z_PROBE_OFFSET_RANGE_MAX 20
#define X_ENABLE_ON 0
#define Y_ENABLE_ON 0
#define Z_ENABLE_ON 0
#define E_ENABLE_ON 0 // For all extruders
#define DISABLE_OTHER_EXTRUDERS   // Keep only the active extruder enabled
#define INVERT_X_DIR false
#define INVERT_Y_DIR true
#define INVERT_Z_DIR false
#define INVERT_E0_DIR false
#define INVERT_E1_DIR false
#define INVERT_E2_DIR false
#define INVERT_E3_DIR false
#define INVERT_E4_DIR false
#define INVERT_E5_DIR false
#define INVERT_E6_DIR false
#define INVERT_E7_DIR false
#define X_HOME_DIR -1
#define Y_HOME_DIR -1
#define Z_HOME_DIR -1
#define X_BED_SIZE 200
#define Y_BED_SIZE 200
#define X_MIN_POS 0
#define Y_MIN_POS 0
#define Z_MIN_POS 0
#define X_MAX_POS X_BED_SIZE
#define Y_MAX_POS Y_BED_SIZE
#define Z_MAX_POS 200
#define MIN_SOFTWARE_ENDSTOPS
  #define MIN_SOFTWARE_ENDSTOP_X
  #define MIN_SOFTWARE_ENDSTOP_Y
  #define MIN_SOFTWARE_ENDSTOP_Z
  #define MIN_SOFTWARE_ENDSTOP_I
  #define MIN_SOFTWARE_ENDSTOP_J
  #define MIN_SOFTWARE_ENDSTOP_K
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

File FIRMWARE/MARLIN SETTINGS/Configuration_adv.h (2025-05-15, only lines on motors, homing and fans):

#define E0_AUTO_FAN_PIN -1
#define E1_AUTO_FAN_PIN -1
#define E2_AUTO_FAN_PIN -1
#define E3_AUTO_FAN_PIN -1
#define E4_AUTO_FAN_PIN -1
#define E5_AUTO_FAN_PIN -1
#define E6_AUTO_FAN_PIN -1
#define E7_AUTO_FAN_PIN -1
#define CHAMBER_AUTO_FAN_PIN -1
#define COOLER_AUTO_FAN_PIN -1
#define HOMING_BUMP_MM      { 5, 5, 2 }       // (linear=mm, rotational=°) Backoff from endstops after first bump
#define HOMING_BUMP_DIVISOR { 2, 2, 4 }       // Re-Bump Speed Divisor (Divides the Homing Feedrate)
#define MICROSTEP_MODES { 32, 32, 32, 32, 32, 32 } // [1,2,4,8,16]
#define ADVANCED_PAUSE_FEATURE
  #define ADVANCED_PAUSE_PURGE_FEEDRATE        3  // (mm/s) Extrude feedrate (after loading). Should be slower than load feedrate.
  #define ADVANCED_PAUSE_PURGE_LENGTH         50  // (mm) Length to extrude after loading.
  #define ADVANCED_PAUSE_RESUME_PRIME          0  // (mm) Extra distance to prime nozzle after returning from park.
#define E0_AUTO_FAN_PIN SYSFAN_PIN  // Asigna el pin del ventilador automático al SYSFAN_PIN

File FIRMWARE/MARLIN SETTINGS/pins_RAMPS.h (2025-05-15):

/**
 * Marlin 3D Printer Firmware
 * Copyright (c) 2020 MarlinFirmware [https://github.com/MarlinFirmware/Marlin]
 *
 * Based on Sprinter and grbl.
 * Copyright (c) 2011 Camiel Gubbels / Erik van der Zalm
 *
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
 */
#pragma once

/**
 * Arduino Mega with RAMPS v1.4 (or v1.3) pin assignments
 * ATmega2560, ATmega1280
 *
 * Applies to the following boards:
 *
 *  RAMPS_14_EFB (Hotend, Fan, Bed)
 *  RAMPS_14_EEB (Hotend0, Hotend1, Bed)
 *  RAMPS_14_EFF (Hotend, Fan0, Fan1)
 *  RAMPS_14_EEF (Hotend0, Hotend1, Fan)
 *  RAMPS_14_SF  (Spindle, Controller Fan)
 *
 *  RAMPS_13_EFB (Hotend, Fan, Bed)
 *  RAMPS_13_EEB (Hotend0, Hotend1, Bed)
 *  RAMPS_13_EFF (Hotend, Fan0, Fan1)
 *  RAMPS_13_EEF (Hotend0, Hotend1, Fan)
 *  RAMPS_13_SF  (Spindle, Controller Fan)
 *
 *  Other pins_MYBOARD.h files may override these defaults
 *
 *  Differences between
 *  RAMPS_13 | RAMPS_14
 *         7 | 11
 */

#if ENABLED(AZSMZ_12864) && DISABLED(ALLOW_SAM3X8E)
  #error "No pins defined for RAMPS with AZSMZ_12864."
#endif

#include "env_validate.h"

// Custom flags and defines for the build
//#define BOARD_CUSTOM_BUILD_FLAGS -D__FOO__

#ifndef BOARD_INFO_NAME
  #define BOARD_INFO_NAME "RAMPS 1.4"
#endif

//
// Servos
//
//#ifndef SERVO0_PIN
//  #ifdef IS_RAMPS_13
//    #define SERVO0_PIN                         7
//  #else
//    #define SERVO0_PIN                        11
//  #endif
//#endif
// #ifndef SERVO1_PIN
//  #define SERVO1_PIN                           6
//#endif
//#ifndef SERVO2_PIN
//  #define SERVO2_PIN                           5
//#endif
//#ifndef SERVO3_PIN
//  #define SERVO3_PIN                           4
//#endif
#define SERVO0_PIN 7
//
// Foam Cutter requirements
//

#if ENABLED(FOAMCUTTER_XYUV)
  #ifndef MOSFET_C_PIN
    #define MOSFET_C_PIN                      -1
  #endif
  #if HAS_CUTTER && !defined(SPINDLE_LASER_ENA_PIN) && NUM_SERVOS < 2
    #define SPINDLE_LASER_PWM_PIN              8  // Hardware PWM
  #endif
  #ifndef Z_MIN_PIN
    #define Z_MIN_PIN                         -1
  #endif
  #ifndef Z_MAX_PIN
    #define Z_MAX_PIN                         -1
  #endif
  #ifndef I_STOP_PIN
    #define I_STOP_PIN                        18  // Z-
  #endif
  #ifndef J_STOP_PIN
    #define J_STOP_PIN                        19  // Z+
  #endif
#endif

//
// Limit Switches
//
#ifndef X_STOP_PIN
  #ifndef X_MIN_PIN
    #define X_MIN_PIN                          3  // X-
  #endif
  #ifndef X_MAX_PIN
    #define X_MAX_PIN                          2  // X+
  #endif
#endif
#ifndef Y_STOP_PIN
  #ifndef Y_MIN_PIN
    #define Y_MIN_PIN                         4  // Y-
  #endif
  #ifndef Y_MAX_PIN
    #define Y_MAX_PIN                         5  // Y+
  #endif
#endif
#ifndef Z_STOP_PIN
  #ifndef Z_MIN_PIN
    #define Z_MIN_PIN                         18  // Z-
  #endif
  #ifndef Z_MAX_PIN
    #define Z_MAX_PIN                         19  // Z+
  #endif
#endif

//
// Z Probe (when not Z_MIN_PIN)
//
#ifndef Z_MIN_PROBE_PIN
  #define Z_MIN_PROBE_PIN                     32
#endif

//
// Steppers
//
#define X_STEP_PIN                            54  // (A0)
#define X_DIR_PIN                             55  // (A1)
#define X_ENABLE_PIN                          38
#ifndef X_CS_PIN
  #define X_CS_PIN                       AUX3_06
#endif

#define Y_STEP_PIN                            60
#define Y_DIR_PIN                             61
#define Y_ENABLE_PIN                          56  // (A2)
#ifndef Y_CS_PIN
  #define Y_CS_PIN                       AUX3_02
#endif

#ifndef Z_STEP_PIN
  #define Z_STEP_PIN                          42 //reasignado para usar el pin 46 para control pwm de luces rgb.
#endif
#ifndef Z_DIR_PIN
  #define Z_DIR_PIN                           48
#endif
#ifndef Z_ENABLE_PIN
  #define Z_ENABLE_PIN                        62
#endif
#ifndef Z_CS_PIN
  #define Z_CS_PIN                       AUX2_06
#endif

#ifndef E0_STEP_PIN
  #define E0_STEP_PIN                         26
#endif
#ifndef E0_DIR_PIN
  #define E0_DIR_PIN                          28
#endif
#ifndef E0_ENABLE_PIN
  #define E0_ENABLE_PIN                       24
#endif
#ifndef E0_CS_PIN
  #define E0_CS_PIN                      AUX2_08
#endif

#ifndef E1_STEP_PIN
  #define E1_STEP_PIN                         36
#endif
#ifndef E1_DIR_PIN
  #define E1_DIR_PIN                          34
#endif
#ifndef E1_ENABLE_PIN
  #define E1_ENABLE_PIN                       30
#endif
#ifndef E1_CS_PIN
  #define E1_CS_PIN                      AUX2_07
#endif

//
// Temperature Sensors
//
#ifndef TEMP_0_PIN
  #define TEMP_0_PIN                          13  // Analog Input
#endif
#ifndef TEMP_1_PIN
  #define TEMP_1_PIN                          15  // Analog Input
#endif
#ifndef TEMP_BED_PIN
  #define TEMP_BED_PIN                        14  // Analog Input
#endif

//
// SPI for MAX Thermocouple
//
#ifndef TEMP_0_CS_PIN
  #define TEMP_0_CS_PIN                  AUX2_09  // Don't use 53 if using Display/SD card (SDSS) or 49 (SD_DETECT_PIN)
#endif
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

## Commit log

2023-07-06 Actualización README.md
    actualización de la información del repositorio en el archivo README.
2023-07-06 Actualizar README.md
    actualización de README.
2023-07-06 Printable parts models
    añadido de la primera variante para las partes imprimibles en 3d.
    [EjeX_polea.stl, EjeX_polea2.stl, Extrusor_12.stl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]
2023-07-06 DIAGRAMAS
    nuevos diagramas añadidos
    [MK8266-O1WF-REV1A.brd, MK8266-O1WF-REV1A.sch, unipolar stepp connect.brd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]
2023-07-06 main pcb controller
    añadida placa principal pcb.
    [MK2560EM-G v1G.brd, MK2560EM-G v1G.sch]
2023-07-06 modelos 3d
    modelos 3d renderizados del aspecto final de la placa.
2023-07-11 new 3d variants
    nuevos modelos 3d para imprimir las partes plasticas.
    [Black_-_Back_Base_Plate.stl, Black_-_Bearing_Holder.stl, Black_-_Extruder_Strain_Relief.stl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]
2023-07-13 new renders and mods
    new 3d rendered pcb images, and also son minor modifications to the pcb layout.
    [MK2560EM-G v1G.brd]
2023-07-25 new pcb circuit files
    nuevos archivos pcb corregidos, y añadido un pcb a color con aambas caras.
2023-07-27 new pcb optimizations
    minor pcb error fixes and optimizations.
    -changed some thermistors capacitors components for bigger ones.
    - added silkscreen pdf for soldering reference.
    [MK2560EM-G v1G.brd, MK2560EM-G v1G.sch]
2023-08-10 new 3d rendered files
    new files update.
    [MK2560EM-G v1G-FLAT_PCB.step]
2023-08-18 pcb fixes v1G.1
    - pcb bug corrections space clearance on x,y,z drivers resolution pin headers. changed for right pin headers.
    - changed F5A fuse for +12v rail, for aa short cylinder standard fuse.
    - pcb resized, for more space, and better alocation of components.
    -
    [MK2560EM-G v1G.1.brd, MK2560EM-G v1G.1.sch]
2023-08-28 updated structure files
    [Black_-_Back_Base_Plate.stl, Black_-_Bearing_Holder.stl, Black_-_Extruder_Strain_Relief.stl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]
2023-09-12 updated new mikroprinter 3d parts
    added updated and new Mikroprinter 3D printable parts.
    [EjeX_polea.stl, EjeX_polea2.stl, Extrusor_12.stl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]
2025-04-05 md and update files
    new updated files uploaded.
    [MK-Bed_v2.stl, MK-Extruder_1.stl, MK-Y_Plate_Front_v1.stl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]
2025-04-13 new parts uploaded!
    added new 3d parts!
    [mk-bed-plate.stl, mk-board-case_v2.stl, mk-cable-clip.stl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]
2025-04-13 updated 3d files
    added new 3d files for printer parts
    [mk-limit-switch-z-mount.stl, mk_z_top.stl]
2025-04-25 new version released
    MK2560EMG V2 RELEASED.
    - new pcb redesign.
    - added new ports and components.
    - improve quality on routes and better use of space. retaining same form factor and siez.
    [MK2560EM-G v2.brd, MK2560EM-G v2.sch, mk-board-case-top.stl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]
2025-04-29 pcb minor fix
    - optimization and minor pcb fix for better design and perfomance.
    [MK2560EM-G v2.brd, MK2560EM-G v2.sch]
2025-04-30 new pcb files
    - updated pcb and sch files!
    - new improvements and funcionality of the controller board.
    [MK2560EM-G v2.brd, MK2560EM-G v2.sch]
2025-05-09 important pcb update
    - added XT60 connectors for bed connection.
    - optimization of some pcb tracks, added support for ext reset button.
    [MK2560EM-G v2.brd, MK2560EM-G v2.sch]
2025-05-15 new pcb update and fixes
    - new pcb fixes and testing for factory pcb production.
    - added picture of pcb components in place.
    - added pdf with the final design of the pcb.
    [MK2560EM-G v2.brd, MK2560EM-G v2.sch]
2025-05-15 firmware and host development.
    - added Marlin configuration files for compiling.
    - initial development of host software in python. it can change in the future.
    [Configuration.h, Configuration_adv.h]

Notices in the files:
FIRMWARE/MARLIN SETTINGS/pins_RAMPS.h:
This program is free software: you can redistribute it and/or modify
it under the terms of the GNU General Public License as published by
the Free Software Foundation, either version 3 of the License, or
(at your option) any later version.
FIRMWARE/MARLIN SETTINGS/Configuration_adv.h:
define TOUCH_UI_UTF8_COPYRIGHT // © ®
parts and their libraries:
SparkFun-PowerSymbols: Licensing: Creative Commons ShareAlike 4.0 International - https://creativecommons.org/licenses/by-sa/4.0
